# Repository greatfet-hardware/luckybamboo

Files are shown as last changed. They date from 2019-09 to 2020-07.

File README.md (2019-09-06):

# Lucky Bamboo
a quadruple 2.4 GHz ADF7242 transceiver GreatFET neighbor for monitoring Bluetooth LE 

Required KiCad dependency:

https://github.com/greatscottgadgets/gsg-kicad-lib

If you are using git, the preferred way to install gsg-kicad-lib is to use the
submodule:

```
git submodule init && git submodule update
```

## Pin usage

signal  | default pin     | alt1  | alt2
--------|---------|-------|-----
SPORT receive data 1    | J2.36 (SGPIO4)   | J2.18 (SGPIO14) |
SPORT receive data 2    | J1.07 (SGPIO7)   | J1.13 (SGPIO15) |
SPORT receive data 3     | J2.33 (SGPIO6)     | J2.29 (SGPIO7) |
SPORT receive data 4       |    J1.30 (SGPIO3)     | J1.37 (SGPIO13) |
SPORT CLK 1       |     J1.21 (SGPIO8)    |     |
SPORT CLK 2       |    J1.26 (SGPIO9)     |     |
SPORT CLK 3       |    J1.25 (SGPIO10)     |     |
SPORT CLK 4       |    J1.32 (SGPIO11)     |      |
SPI CS 1       |     J2.09    | J2.07 |
SPI CS 2       |     J1.14    | J1.16 |
SPI CS 3       |     J2.31    | J2.24 |
SPI CS 4       |     J1.34    | J1.33 |
SPI CLK       |    J1.38     |     |
SPI SI       |     J1.39    |      |
SPI SO       |    J1.40     |      |
RF switch 1       |   J2.19      |       |
RF switch 2       |    J2.23     |       |
RF switch 3       |    J2.25     |       |
RF switch 4       |    J2.27     |       |
IRQ1 1       |   2x4 header      |   J2.15    |
IRQ1 2       |    2x4 header     |   J1.18     |
IRQ1 3       |    2x4 header     |    J2.34   |
IRQ1 4       |    2x4 header     |   J1.35    |
IRQ2/TRFS 1       |   2x4 header      | J2.16      |
IRQ2/TRFS 2       |    2x4 header     |   J1.3    |
IRQ2/TRFS 3       |    2x4 header     |    J2.35   |
IRQ2/TRFS 4       |    2x4 header     |   J1.28    |

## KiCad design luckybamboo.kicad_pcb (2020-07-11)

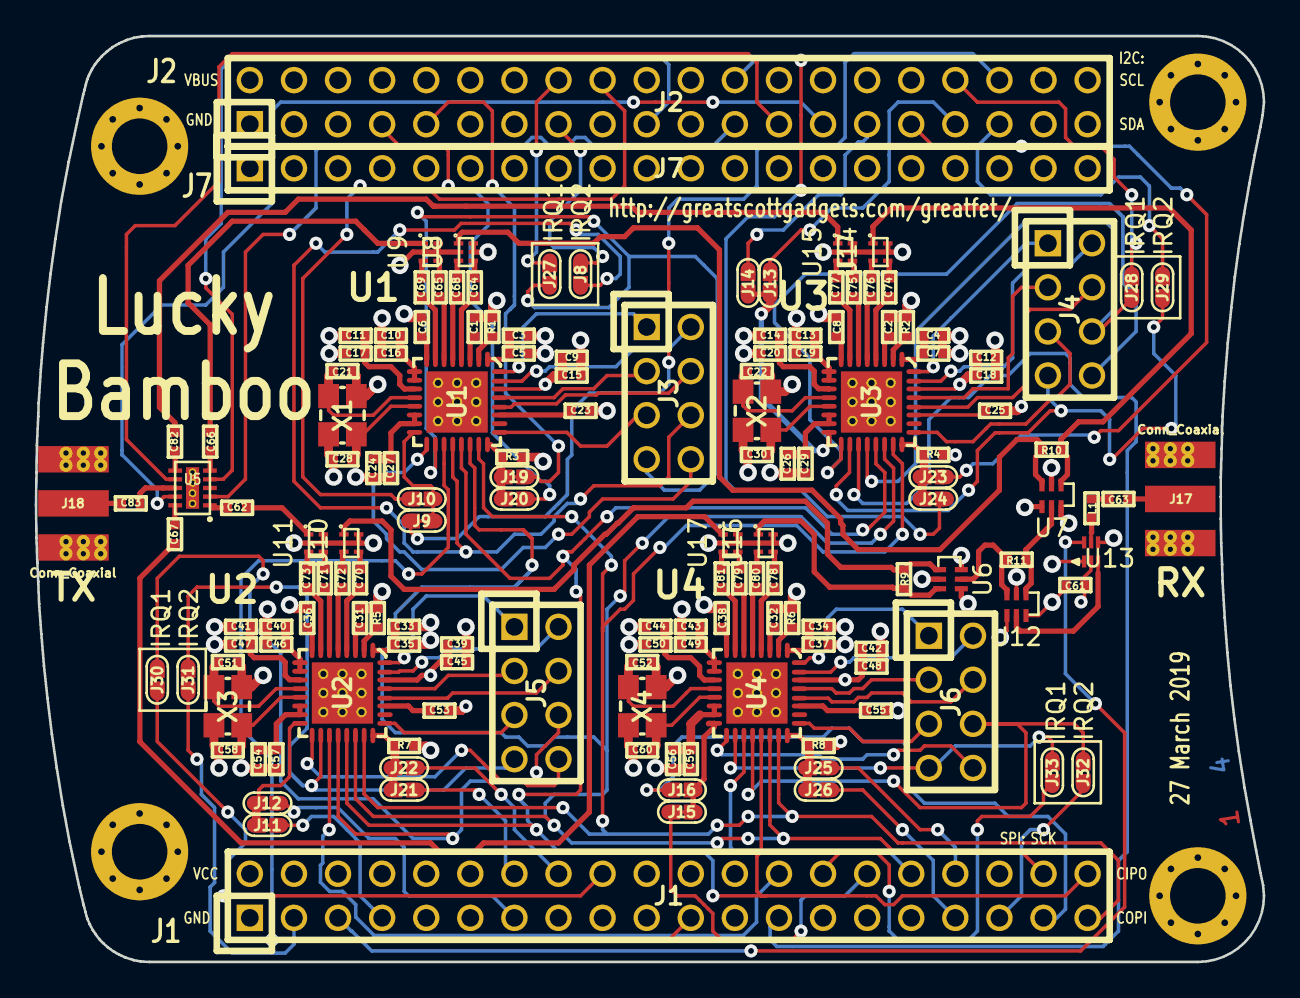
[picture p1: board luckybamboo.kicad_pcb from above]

Board: 4 copper layers, 70.7 x 53.3 mm, 153 parts (0 on the bottom side), 162 nets.

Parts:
C1, C2, C6, C8, C31, C32, C36, C38: 100pF; 0402
C3, C4, C9, C10, C11, C12, C13, C14, C24, C26, C33, C34, C39, C40, C41, C42, C43, C44, C54, C56: 220nF; 0402
C5, C7, C15, C16, C17, C18, C19, C20, C27, C29, C35, C37, C45, C46, C47, C48, C49, C50, C57, C59: 27pF; 0402
C21, C22, C28, C30, C51, C52, C58, C60: 18pF; 0402
C23, C25, C53, C55, C61, C63: 1nF; 0402
C62, C66, C67, C82, C83: 47pF; 0402
C64, C65, C68, C69, C70, C71, C72, C73, C74, C75, C76, C77, C78, C79, C80, C81: 10nF; 0402
J1: NEIGHBOR1; HEADER-2x20
J2: NEIGHBOR2; HEADER-2x20
J3, J4, J5, J6: Conn_01x08; HEADER-2x4
J7: BONUS_ROW; HEADER-1x20
J8, J9, J10, J11, J12, J13, J14, J15, J16, J19, J20, J21, J22, J23, J24, J25, J26, J27, J28, J29, J30, J31, J32, J33: TEST_2P; 0603-JUMPER
J17, J18: Conn_Coaxial; SMA-EDGE
L1: 3.8nH; 0402
MH1, MH2, MH3, MH4: MOUNTING_HOLE; HOLE126MIL-COPPER
R1, R2, R5, R6: 27k; 0402
R3, R4, R7, R8: 10k; 0402
R9, R10, R11: 100; 0402
U1, U2, U3, U4: ADF7242; LFCSP32
U5: SKY13322; SKY13322-375LF
U6, U7, U12: HHM2293A1
U8, U9, U10, U11, U14, U15, U16, U17: ADF7242_balun
U13: BGA7H1N6
X1, X2, X3, X4: XTAL4PIN; XTAL3.2x2.5mm

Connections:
/DR1: J2.36, J9.1, J9.2, J10.1, U1.16
/DR2: J1.7, J11.1, J11.2, J12.1, U2.16
/DR3: J2.33, J13.1, J13.2, J14.1, U3.16
/DR4: J1.30, J15.1, J15.2, J16.1, U4.16
/DT1: J3.8, U1.17
/DT2: J5.8, U2.17
/DT3: J4.8, U3.17
/DT4: J6.8, U4.17
/IRQ1: J3.6, J8.2, U1.20
/IRQ2: J5.6, J30.2, U2.20
/IRQ3: J4.6, J28.2, U3.20
/IRQ4: J6.6, J32.2, U4.20
/P1_3: J1.40, U1.21, U2.21, U3.21, U4.21
/P1_4: J1.39, U1.23, U2.23, U3.23, U4.23
/P1_5: J1.13, J12.2
/P1_6: J1.16, J22.2
/P1_8: J1.18, J30.1
/P1_12: J1.21, U1.19
/P1_13: J1.26, U2.19
/P1_14: J1.25, U3.19
/P1_15: J1.28, J33.1
/P1_17: J1.32, U4.19
/P1_19: J1.38, U1.22, U2.22, U3.22, U4.22
/P1_20: J1.37, J16.2
/P2_0: J1.35, J32.1
/P2_1: J2.35, J29.1
/P2_4: J2.19, U5.4
/P2_5: J2.18, J10.2
/P2_6: J2.15, J8.1
/P3_1: J2.24, J24.2
/P4_3: J2.9, J19.1, J19.2, J20.1, R3.2, U1.24
/P4_4: J2.7, J20.2
/P4_9: J1.3, J31.1
/P4_10: J1.5, U13.6
/P5_2: J1.14, J21.1, J21.2, J22.1, R7.2, U2.24
/P6_6: J2.34, J28.1
/P6_7: J2.31, J23.1, J23.2, J24.1, R4.2, U3.24
/P6_8: J2.29, J14.2
/P7_0: J2.27, U5.9
/P7_1: J2.25, U5.7
/P7_2: J2.23, U5.2
/P7_7: J2.16, J27.1
/P9_5: J1.33, J26.2
/P9_6: J1.34, J25.1, J25.2, J26.1, R8.2, U4.24
/PABIAOP1: J3.1, U1.32
/PABIAOP2: J5.1, U2.32
/PABIAOP3: J4.1, U3.32
/PABIAOP4: J6.1, U4.32
/PAVSUP1: J3.2, U1.31
/PAVSUP2: J5.2, U2.31
/PAVSUP3: J4.2, U3.31
/PAVSUP4: J6.2, U4.31
/RFIN: L1.1, U13.5
/RFIN1: R10.1, U7.3, U8.1
/RFIN1_N: C68.2, U1.5
/RFIN1_P: C64.2, U1.4
/RFIN2: R9.2, U6.1, U10.1
/RFIN2_N: C72.2, U2.5
/RFIN2_P: C70.2, U2.4
/RFIN3: R10.2, U7.1, U14.1
/RFIN3_N: C76.2, U3.5
/RFIN3_P: C74.2, U3.4
/RFIN4: R9.1, U6.3, U16.1
/RFIN4_N: C80.2, U4.5
/RFIN4_P: C78.2, U4.4
/RFOUT1: C66.2, U9.1
/RFOUT1_N: C69.2, U1.7
/RFOUT1_P: C65.2, U1.6
/RFOUT2: C62.1, U11.1
/RFOUT2_N: C73.2, U2.7
/RFOUT2_P: C71.2, U2.6
/RFOUT3: C82.1, U15.1
/RFOUT3_N: C77.2, U3.7
/RFOUT3_P: C75.2, U3.6
/RFOUT4: C67.2, U17.1
/RFOUT4_N: C81.2, U4.7
/RFOUT4_P: C79.2, U4.6
/TRFS1: J3.7, J27.2, U1.18
/TRFS2: J5.7, J31.2, U2.18
/TRFS3: J4.7, J29.2, U3.18
/TRFS4: J6.7, J33.2, U4.18
/TXEN1: J3.5, U1.25
/TXEN2: J5.5, U2.25
/TXEN3: J4.5, U3.25
/TXEN4: J6.5, U4.25
/XOSC32KN1: J3.3, U1.29
/XOSC32KN2: J5.3, U2.29
/XOSC32KN3: J4.3, U3.29
/XOSC32KN4: J6.3, U4.29
/XOSC32KP1: J3.4, U1.28
/XOSC32KP2: J5.4, U2.28
/XOSC32KP3: J4.4, U3.28
/XOSC32KP4: J6.4, U4.28
GND: C1.1, C2.1, C3.1, C4.1, C5.1, C6.2, C7.1, C8.2, C9.1, C10.2, C11.2, C12.1, C13.2, C14.2, C15.1, C16.2, C17.2, C18.1, C19.2, C20.2, C21.2, C22.2, C23.1, C24.2, C25.1, C26.2, C27.2, C28.2, C29.2, C30.2, C31.1, C32.1, C33.1, C34.1, C35.1, C36.2, C37.1, C38.2, C39.1, C40.2, C41.2, C42.1, C43.2, C44.2, C45.1, C46.2, C47.2, C48.1, C49.2, C50.2, C51.2, C52.2, C53.1, C54.2, C55.1, C56.2, C57.2, C58.2, C59.2, C60.2, C61.1, J1.1, J2.1, J7.1, J7.10, J7.19, J17.2, J18.2, MH1.1, MH2.1, MH3.1, MH4.1, R1.1, R2.1, R5.1, R6.1, U1.0, U2.0, U3.0, U4.0, U5.0, U6.2, U6.4, U6.6, U7.2, U7.4, U7.6, U8.2, U8.5, U8.6, U9.2, U9.5, U9.6, U10.2, U10.5, U10.6, U11.2, U11.5, U11.6, U12.2, U12.4, U12.6, U13.1, U13.4, U14.2, U14.5, U14.6, U15.2, U15.5, U15.6, U16.2, U16.5, U16.6, U17.2, U17.5, U17.6, X1.2, X1.4, X2.2, X2.4, X3.2, X3.4, X4.2, X4.4
unnamed: C1.2, U1.3
unnamed: C2.2, U3.3
unnamed: C3.2, C5.2, U1.1
unnamed: C4.2, C7.2, U3.1
unnamed: C6.1, U1.8
unnamed: C8.1, U3.8
unnamed: C10.1, C16.1, U1.9, U1.10
unnamed: C11.1, C17.1, U1.11
unnamed: C13.1, C19.1, U3.9, U3.10
unnamed: C14.1, C20.1, U3.11
unnamed: C21.1, U1.12, X1.1
unnamed: C22.1, U3.12, X2.1
unnamed: C23.2, U1.27
unnamed: C24.1, C27.1, U1.14, U1.15
unnamed: C25.2, U3.27
unnamed: C26.1, C29.1, U3.14, U3.15
unnamed: C28.1, U1.13, X1.3
unnamed: C30.1, U3.13, X2.3
unnamed: C31.2, U2.3
unnamed: C32.2, U4.3
unnamed: C33.2, C35.2, U2.1
unnamed: C34.2, C37.2, U4.1
unnamed: C36.1, U2.8
unnamed: C38.1, U4.8
unnamed: C40.1, C46.1, U2.9, U2.10
unnamed: C41.1, C47.1, U2.11
unnamed: C43.1, C49.1, U4.9, U4.10
unnamed: C44.1, C50.1, U4.11
unnamed: C51.1, U2.12, X3.1
unnamed: C52.1, U4.12, X4.1
unnamed: C53.2, U2.27
unnamed: C54.1, C57.1, U2.14, U2.15
unnamed: C55.2, U4.27
unnamed: C56.1, C59.1, U4.14, U4.15
unnamed: C58.1, U2.13, X3.3
unnamed: C60.1, U4.13, X4.3
unnamed: C62.2, U5.1
unnamed: C63.1, L1.2
unnamed: C63.2, J17.1
unnamed: C64.1, U8.4
unnamed: C65.1, U9.4
unnamed: C66.1, U5.5
unnamed: C67.1, U5.10
unnamed: C68.1, U8.3
unnamed: C69.1, U9.3
unnamed: C70.1, U10.4
unnamed: C71.1, U11.4
unnamed: C72.1, U10.3
unnamed: C73.1, U11.3
unnamed: C74.1, U14.4
unnamed: C75.1, U15.4
unnamed: C76.1, U14.3
unnamed: C77.1, U15.3
unnamed: C78.1, U16.4
unnamed: C79.1, U17.4
unnamed: C80.1, U16.3
unnamed: C81.1, U17.3
unnamed: C82.2, U5.6
unnamed: C83.1, U5.8
unnamed: C83.2, J18.1
unnamed: R1.2, U1.2
unnamed: R2.2, U3.2
unnamed: R5.2, U2.2
unnamed: R6.2, U4.2
unnamed: R11.1, U6.5, U12.3
unnamed: R11.2, U7.5, U12.1
unnamed: U12.5, U13.3
VCC: C9.2, C12.2, C15.2, C18.2, C39.2, C42.2, C45.2, C48.2, C61.2, J1.2, J7.20, R3.1, R4.1, R7.1, R8.1, U1.30, U2.30, U3.30, U4.30, U13.2

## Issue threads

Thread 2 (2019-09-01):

Add I/O expander

mossmann, 2019-09-01:
Use I2C for neighbor identification and to reduce GPIO pin usage.

mossmann, 2019-09-01:
This should also clear up some nets that have multiple names in the schematic.

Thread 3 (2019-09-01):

add voltage regulator

mossmann, 2019-09-01:
Max current consumption is around 100 mA which is on the high side for stacking with other neighbors. Add a regulator supplied by +5V that can be switched off.

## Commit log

2019-05-27 split luckybamboo into separate repository
    [azalea.kicad_pcb, azalea.sch, begonia.kicad_pcb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]
2020-07-03 adopt OSHWA convention for SPI signal names https://www.oshwa.org/a-resolution-to-redefine-spi-signal-names
    [luckybamboo.kicad_pcb, luckybamboo.sch]

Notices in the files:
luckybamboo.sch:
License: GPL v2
